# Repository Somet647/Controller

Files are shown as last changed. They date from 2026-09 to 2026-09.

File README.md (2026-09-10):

# Custom ATmega32U4 USB HID Gamepad

A custom USB gamepad designed and built around an ATmega32U4 microcontroller. This project started as a breadboard prototype using an Arduino and was developed into a standalone custom PCB, combining embedded firmware, digital and analog inputs, USB HID communication, and PCB design.

---

## Features

### Hardware & PCB Design
* **Custom ATmega32U4 Design:** Designed a standalone gamepad around the ATmega32U4, integrating the microcontroller, clock circuitry, USB interface, programming header, analog inputs, and digital inputs onto a custom PCB.
* **USB-C Interface:** Implemented a USB-C device interface with 5.1kΩ CC pull-down resistors, 22Ω D+/D− series resistors, and dedicated power decoupling for reliable communication.
* **Analog Input System:** Integrated analog data processing using the ATmega32U4's ADC channels to provide joystick functionality.
* **Power & Decoupling:** Distributed the +5V USB supply across the board with local 100nF and bulk 10μF capacitors to reduce noise and add stability.
* **External Clock:** Implemented a 16MHz crystal oscillator with 22pF load capacitors to provide the ATmega32U4 with a stable system clock.
* **ISP Programming:** Added a dedicated 6-pin AVR ISP header for directly programming the ATmega32U4 on the custom PCB.
* **PCB Layout:** Designed the complete schematic and multi-layer PCB layout in KiCad.

### Firmware
* **Standalone USB HID:** Configured the ATmega32U4 as a USB HID gamepad, providing direct PC compatibility without a secondary USB-to-UART bridge or custom PC software.
* **Analog Input Handling:** Used the ATmega32U4's 10-bit ADC to support 2 analog joysticks across 4 axes (X, Y, Rx, Ry).
* **Digital Input Handling:** Configured 14 button inputs using the MCU's internal pull-up resistors and active-low logic, eliminating the need for external pull-up components.
* **Low-Latency Input**: Sampled button and analog inputs at approximately 100 Hz using a 10 ms control loop for responsive controller input.
* **Input Mapping:** Developed a software mapping between the ATmega32U4 GPIO/ADC pins and the corresponding gamepad buttons and analog axes.

---

## Hardware Specifications

| Component | Specification |
| --- | --- |
| **MCU** | ATmega32U4 |
| **Supply** | 5 V from USB |
| **USB Connector** | USB-C |
| **USB Data** | D+ / D− with 22 Ω series resistors |
| **CC Configuration** | 5.1 kΩ pull-downs on CC1/CC2 |
| **Digital Inputs** | 14 buttons, internal pull-ups |
| **Analog Inputs** | 4 × 10-bit ADC channels |
| **Analog Controls**  | 2 × dual-axis joysticks |
| **System Clock** | 16 MHz external crystal |
| **ISP** | 6-pin AVR ISP header |
| **PCB** | Custom multi-layer PCB |
| **Design Software**  | KiCad |

---

## Repository Structure

```text
├── firmware/         # C++ / Arduino controller logic and USB HID descriptors
├── hardware/         # KiCad schematics, PCB board layout, and Gerber manufacturing files
└── README.md         # Project technical summary

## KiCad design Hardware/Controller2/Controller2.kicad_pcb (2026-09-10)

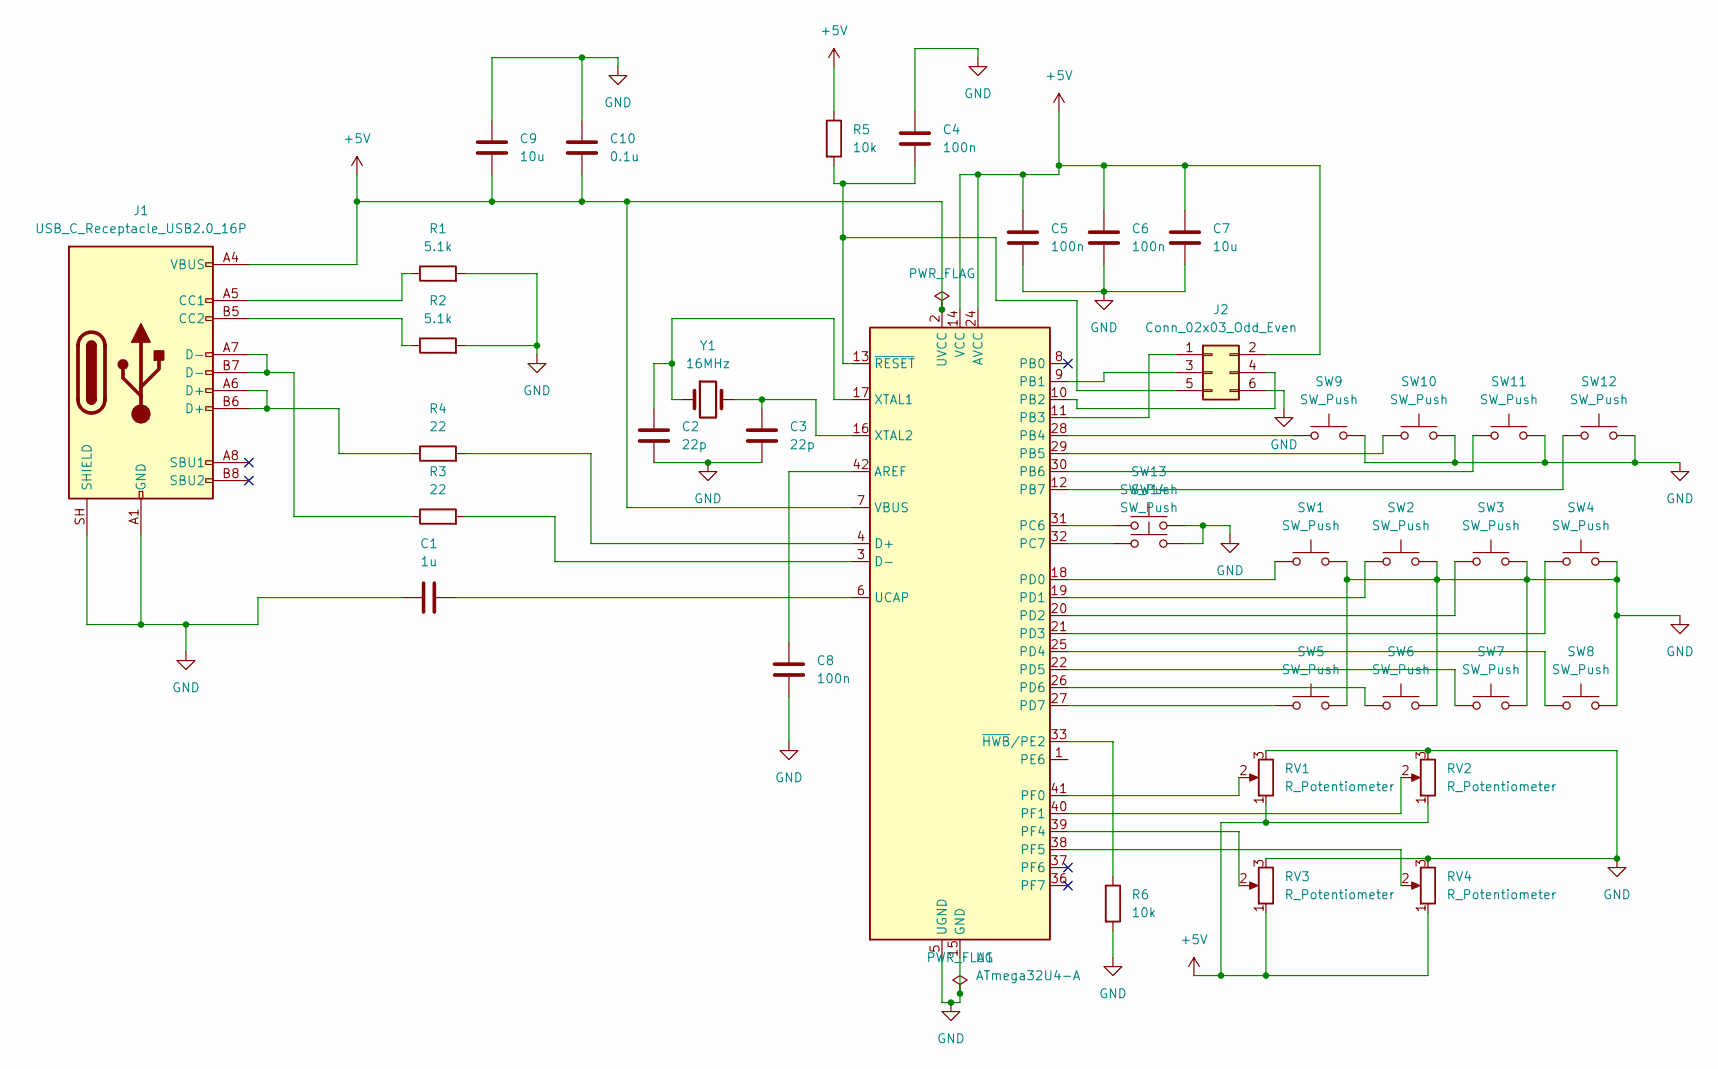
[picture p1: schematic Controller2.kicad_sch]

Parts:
C1: 1u; C_0805_2012Metric
C2, C3: 22p; C_0805_2012Metric
C4, C5, C6, C8: 100n; C_0805_2012Metric
C7, C9: 10u; C_0805_2012Metric
C10: 0.1u; C_0805_2012Metric
J1: USB_C_Receptacle_USB2.0_16P; USB_C_Receptacle_GCT_USB4085
J2: Conn_02x03_Odd_Even; PinHeader_2x03_P2.54mm_Vertical
R1, R2: 5.1k; R_0805_2012Metric
R3, R4: 22; R_0805_2012Metric
R5, R6: 10k; R_0805_2012Metric
RV1, RV2, RV3, RV4: R_Potentiometer; PinHeader_1x03_P2.54mm_Vertical
SW1, SW2, SW3, SW4, SW5, SW6, SW7, SW8, SW9, SW10, SW11, SW12, SW13, SW14: SW_Push; SW_PUSH_6mm
U1: ATmega32U4-A; TQFP-44_10x10mm_P0.8mm
Y1: 16MHz; Crystal_SMD_3225-4Pin_3.2x2.5mm

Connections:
+5V: C5.1, C6.1, C7.1, C9.2, C10.2, J1.A4 (VBUS), J1.A9 (VBUS), J1.B4 (VBUS), J1.B9 (VBUS), J2.2, R5.1, RV1.1, RV2.1, RV3.1, RV4.1, U1.2 (UVCC), U1.7 (VBUS), U1.14 (VCC), U1.24 (AVCC), U1.34 (VCC), U1.44 (AVCC)
GND: C1.1, C2.2, C3.2, C4.1, C5.2, C6.2, C7.2, C8.2, C9.1, C10.1, J1.A1 (GND), J1.A12 (GND), J1.B1 (GND), J1.B12 (GND), J1.SH (SHIELD), J2.6, R1.2, R2.2, R6.2, RV1.3, RV2.3, RV3.3, RV4.3, SW1.2, SW2.2, SW3.2, SW4.2, SW5.2, SW6.2, SW7.2, SW8.2, SW9.2, SW10.2, SW11.2, SW12.2, SW13.2, SW14.2, U1.5 (UGND), U1.15 (GND), U1.23 (GND), U1.35 (GND), U1.43 (GND)
unnamed: J1.A5 (CC1), R1.1
unnamed: J1.B5 (CC2), R2.1
unnamed: J1.A6 (D+), J1.B6 (D+), R4.1
unnamed: J1.A7 (D-), J1.B7 (D-), R3.1
unnamed: J2.1, U1.11 (PB3)
unnamed: J2.3, U1.9 (PB1)
unnamed: J2.4, U1.10 (PB2)
unnamed: C4.2, J2.5, R5.2, U1.13 (~RESET)
unnamed: C8.1, U1.42 (AREF)
unnamed: R4.2, U1.4 (D+)
unnamed: R3.2, U1.3 (D-)
unnamed: SW9.1, U1.28 (PB4)
unnamed: SW10.1, U1.29 (PB5)
unnamed: SW11.1, U1.30 (PB6)
unnamed: SW12.1, U1.12 (PB7)
unnamed: SW13.1, U1.31 (PC6)
unnamed: SW14.1, U1.32 (PC7)
unnamed: SW1.1, U1.18 (PD0)
unnamed: SW2.1, U1.19 (PD1)
unnamed: SW3.1, U1.20 (PD2)
unnamed: SW4.1, U1.21 (PD3)
unnamed: SW8.1, U1.25 (PD4)
unnamed: SW7.1, U1.22 (PD5)
unnamed: SW6.1, U1.26 (PD6)
unnamed: SW5.1, U1.27 (PD7)
unnamed: RV1.2, U1.41 (PF0)
unnamed: RV2.2, U1.40 (PF1)
unnamed: RV3.2, U1.39 (PF4)
unnamed: RV4.2, U1.38 (PF5)
unnamed: C1.2, U1.6 (UCAP)
unnamed: C2.1, U1.17 (XTAL1), Y1.1
unnamed: C3.1, U1.16 (XTAL2), Y1.2
unnamed: R6.1, U1.33 (~HWB/PE2)

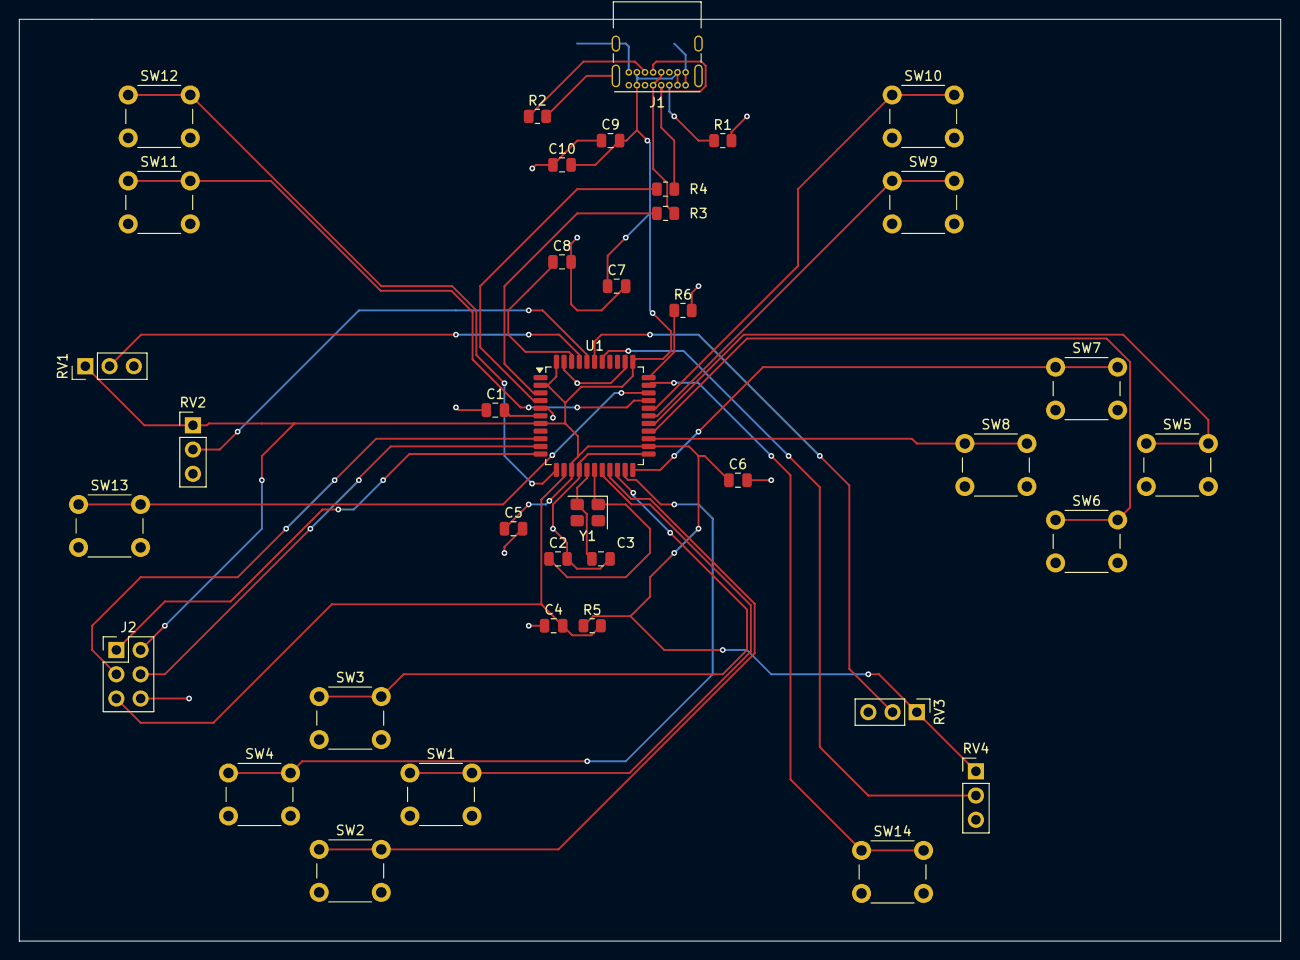
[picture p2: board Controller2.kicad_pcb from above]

Board: 2 copper layers, 132.1 x 96.5 mm, 38 parts (0 on the bottom side), 35 nets.

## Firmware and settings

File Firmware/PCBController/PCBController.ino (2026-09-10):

#include <Joystick.h>

// Initialize Gamepad with 14 buttons and 2 dual-axis joysticks (X, Y, Rx, Ry)
Joystick_ Joystick(JOYSTICK_DEFAULT_REPORT_ID, 
  JOYSTICK_TYPE_GAMEPAD, 
  14, 0,                 // 14 Buttons, 0 Hat Switches
  true, true, false,     // Joystick 1: X Axis, Y Axis
  true, true, false,     // Joystick 2: Rx Axis, Ry Axis
  false, false,          // No rudder or throttle
  false, false, false);  // No accelerator, brake, or steering

// Arduino IDE pins mapped from ATmega32U4 physical pins:
// [28, 29, 30, 12, 18, 19, 20, 21, 25, 22, 26, 27] + [31, 32]
const int buttonPins[14] = {
  8,  9, 10, 11, // Pins 28, 29, 30, 12
  3,  2,  0,  1, // Pins 18, 19, 20, 21
  4, 30, 12,  6, // Pins 25, 22, 26, 27
  5, 13          // Pins 31, 32 (Joystick Click Buttons)
};

// Potentiometer Analog Pins
const int joy1X = A5; // IC Pin 41
const int joy1Y = A4; // IC Pin 40
const int joy2X = A3; // IC Pin 39
const int joy2Y = A2; // IC Pin 38

void setup() {
  // Configure all 14 button pins as pull up
  for (int i = 0; i < 14; i++) {
    pinMode(buttonPins[i], INPUT_PULLUP);
  }

  //Begin joystick library
  Joystick.begin();
  
  //Set joystick range (0-1023)
  Joystick.setXAxisRange(0, 1023);
  Joystick.setYAxisRange(0, 1023);
  Joystick.setRxAxisRange(0, 1023);
  Joystick.setRyAxisRange(0, 1023);
}

void loop() {
  // Re-assert PD5 (ATmega Pin 22 / Arduino Pin 30) as INPUT with internal PULLUP
  DDRD &= ~(1 << 5);  // Clear direction bit (sets as INPUT)
  PORTD |= (1 << 5);  // Set port bit (enables internal Pull-up)

  //Read Buttons
  for (int i = 0; i < 14; i++) {
    Joystick.setButton(i, !digitalRead(buttonPins[i]));
  }

  //Read Joysticks
  Joystick.setXAxis(analogRead(joy1X));   
  Joystick.setYAxis(analogRead(joy1Y));   
  Joystick.setRxAxis(analogRead(joy2X));  
  Joystick.setRyAxis(analogRead(joy2Y));  

  delay(10); 
}

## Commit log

2026-09-10 Update .gitignore to include Arduino
2026-09-10 Initial commit: Add hardware design and Arduino firmware
    [Controller2-B_Cu.gbr, Controller2-B_Mask.gbr, Controller2-B_Paste.gbr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]
2026-09-10 Deleted Backup Directory
    [Controller2.kicad_pcb, Controller2.kicad_sch]
2026-09-10 Add hardware directory
    [Controller2-B_Cu.gbr, Controller2-B_Mask.gbr, Controller2-B_Paste.gbr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]
